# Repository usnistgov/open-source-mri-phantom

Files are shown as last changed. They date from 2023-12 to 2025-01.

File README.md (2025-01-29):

# Open Source NIST Phantom

Repository to host the open-source NIST phantom. 

## CAD Files for 3D Printing

STL files that can be used for 3d printing are located in the 
[stl-files](https://github.com/usnistgov/open-source-mri-phantom/tree/main/stl-files) directory.

Files that can be used for modifying the CAD design of the phantom are located in the 
[stp-files](https://github.com/usnistgov/open-source-mri-phantom/tree/main/stp-files) directory.

Fusion 360 files that can be used for modifying the CAD design of the phantom are located in the 
[f3d-files](https://github.com/usnistgov/open-source-mri-phantom/tree/main/f3d-files) directory.

## Components
A bill of materials is included in this repository. Specifically, additional components for the phantom can be found at:
* 1x [Oil-Resistant Buna-N O-Ring, 4 mm Wide, 155 mm Inner Diameter](https://www.mcmaster.com/1302N303/)
* 10x [Nylon Plastic Socket Head Screw, M4 x 0.70 mm Thread, 14 mm Long](https://www.mcmaster.com/93640A129/)
* Fill plug, either of:
    * 1x [Plug with External Hex Drive Style, 1/8 NPT](https://www.mcmaster.com/45505K195/)
    * 1x [Plug with External Hex Drive, M10 X1.5 mm Thread Male](https://www.mcmaster.com/4956N25/)

## Tools
* 3.5mm Allen wrench for bolts
* Adjustable wrench for fill plugs
* Bolts:
    * Metric tap: M4 x 0.7
    * (Optional) 3.3mm drill bit
* NPT fill plug:
    * NPT tap (if using NPT fill plug): size: 1/8; threads per inch: 27
    * (Optional) Q drill bit
* Metric fill plug:
    * Metric tap: M10 x 1.5
    * (Optional) 8.5mm drill bit

## Assembly
1. If printing with water permeable material, you may want to coat the inside of the phantom with a waterproof 
layer. [Plasti Dip](https://plastidip.com/our-products/plasti-dip/) can work well for this.
1. The bolt holes and fill port may need to be expanded if the 3D print resulted in a narrower hole. If so, drill out
the holes using the tools described above.
1. Tap the bolt holes and fill port.

## Software
Python code to analyze geometric distortion, snr, and cnr is provided in the [python](https://github.com/usnistgov/open-source-mri-phantom/tree/main/python) directory.

---

This repository is developed and maintained
by the Magnetic Imaging group, principally:

- Kathryn Keenan, @katykeenan-nist

Please reach out with questions and comments.

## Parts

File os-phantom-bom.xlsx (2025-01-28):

Part number | Name | Description | Quantity | Manufacturer | Secondary part number | Secondary part name | Secondary part quantity | Secondary part manufacturer
1302N303 | Oil-Resistant Buna-N O-Ring, 4 mm Wide, 155 mm Inner Diameter | O-ring to seal phantom | 1 | McMaster-Carr
93640A146 | Nylon Plastic Socket Head Screw, M4 x 0.70 mm Thread, 14 mm Long | Screws to secure lid | 10 | McMaster-Carr
45505K195 | Plug with External Hex Drive Style, 1/8 NPT | Plug for fill port | 1 | McMaster-Carr | 4956N25 | Plug with External Hex Drive, M10 X1.5 mm Thread Male | 1 | McMaster-Carr

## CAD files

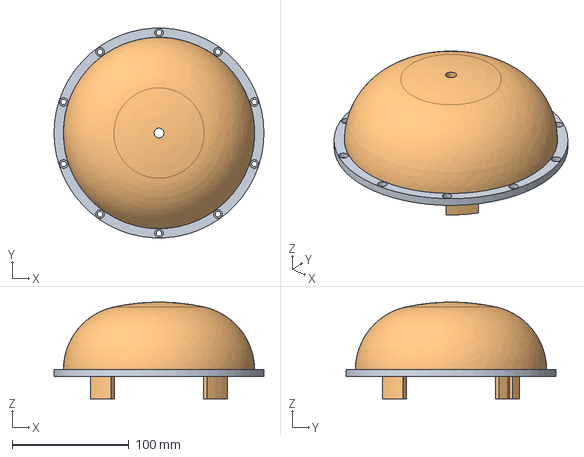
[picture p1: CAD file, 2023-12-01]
stp-files/OS-NIST-lid-domed.step
180.0 x 179.7 x 83.0 mm

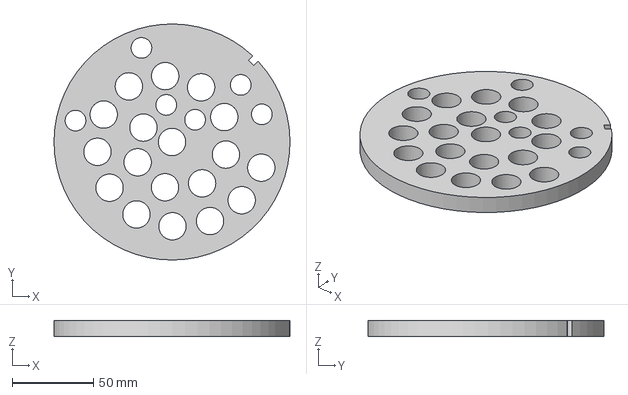
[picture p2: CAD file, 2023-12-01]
stp-files/OS-NIST-plate-axial.step
145.0 x 145.0 x 10.0 mm

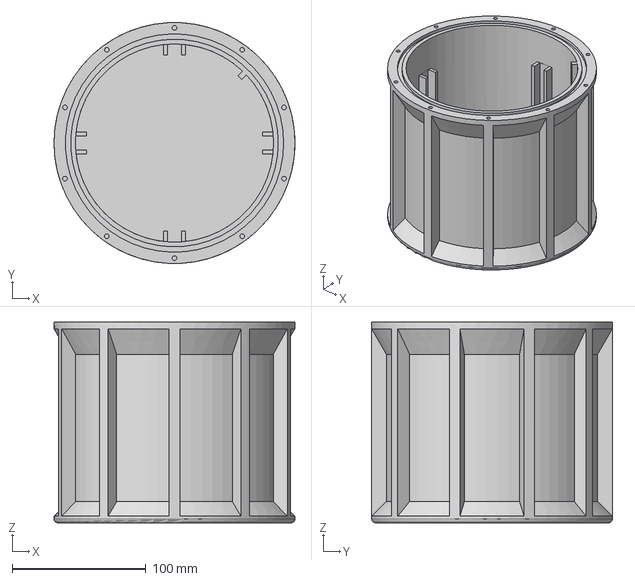
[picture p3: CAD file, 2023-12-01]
stp-files/OS-NIST-bottom.step
180.0 x 179.8 x 150.0 mm

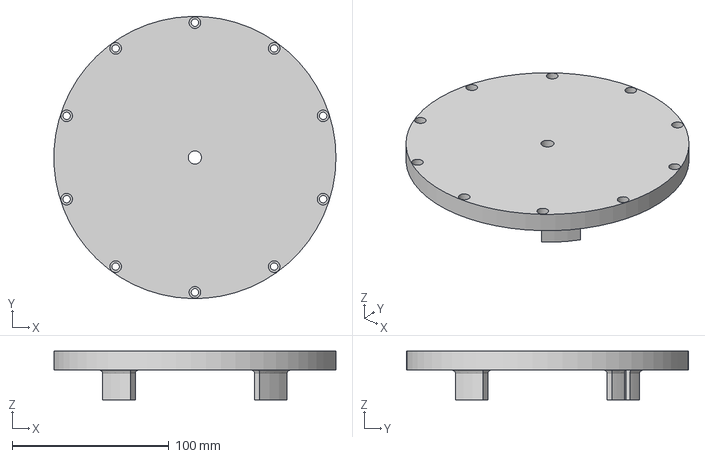
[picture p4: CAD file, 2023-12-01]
stp-files/OS-NIST-lid-flat.step
179.9 x 179.9 x 31.0 mm

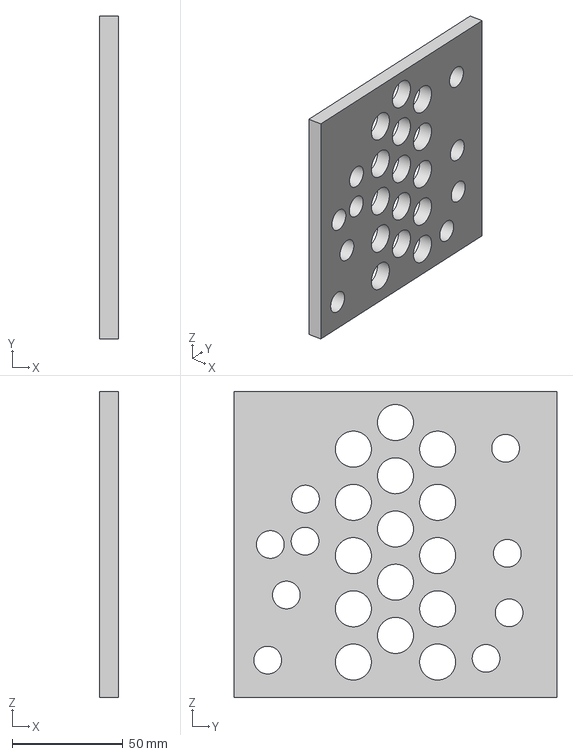
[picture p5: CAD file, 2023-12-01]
stp-files/OS-NIST-plate-cor-sag.step
8.40 x 145.6 x 138.0 mm

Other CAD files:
f3d-files/OS-NIST-bottom.f3d
f3d-files/OS-NIST-lid-domed.f3d
f3d-files/OS-NIST-lid-flat.f3d
f3d-files/OS-NIST-plate-axial.f3d
f3d-files/OS-NIST-plate-cor-sag.f3d
stl-files/OS-NIST-bottom.stl
stl-files/OS-NIST-lid-domed.stl
stl-files/OS-NIST-lid-flat.stl
stl-files/OS-NIST-plate-axial.stl
stl-files/OS-NIST-plate-cor-sag.stl

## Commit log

2023-12-01 Initial commit
    Initial commit of repo specific files, replacing template files
    [OS-NIST-bottom.step, OS-NIST-bottom.stl, OS-NIST-lid-domed.step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]
2023-12-01 Update README.md
    Updated links to stl and stp folders
2025-01-28 Add files via upload
    Updates, mostly additional details, following manuscript revision
    [OS-NIST-bottom.f3d, OS-NIST-lid-domed.f3d, OS-NIST-lid-flat.f3d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]
